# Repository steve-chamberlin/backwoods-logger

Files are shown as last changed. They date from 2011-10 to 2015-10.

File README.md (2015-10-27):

 
 




The Backwoods Logger is a programmable device for measuring and graphing temperature, air pressure, and altitude. It's designed for hikers, backpackers, climbers, skiers, trail runners, cyclists, kayakers, snowmobilers, horseback riders, and other outdoorsy people interested in environmental data logging over timescales from an hour to a few weeks.

Please visit the [wiki](https://github.com/steve-chamberlin/backwoods-logger/wiki) for complete details and documentation.

#### Features ####
  * Graphs of temperature, pressure, and altitude over time
  * Three graph time scales: past 2 hours, past 10 hours, past 2.5 days
  * Current rate of ascent/descent
  * Estimated time of arrival at a user-defined altitude
  * Weather forecast
  * Station pressure and pressure at sea level
  * Snapshot feature – make a permanent record of date, time, altitude, temperature, and pressure at important waypoints
  * Current date and time display
  * Imperial or metric units option
  * Battery voltage indicator
  * Sound on/off control
  * 3 to 6 month battery life, depending on usage
  * Temperature measurements in 0.5 degree steps, from -10F to 117.5F (-23C to 48C)
  * Air pressure measurements in 0.01 in-Hg steps, from 5.9 to 36.12 in-Hg (170 to 1250 millibars)
  * Altitude (calculated from air pressure) measurements in 2 ft steps, from -1384 ft to 14999 ft (-300 to 4500 meters)
  * Download graph data to your PC using the optional [BLsync](https://github.com/steve-chamberlin/backwoods-logger/wiki/BLsync) adapter

Don't see the feature you want? Join the project and help create it! Also check out the list of [development ideas](https://github.com/steve-chamberlin/backwoods-logger/wiki/Development-Needs) for suggestions on where you could help out.

Two versions of the Backwoods Logger design are available:

#### Logger Mini ####
![](http://www.bigmessowires.com/new-logger-mini-graph-300.png)
  * 128 x 64 OLED display
  * 1.9 x 1.1 x 0.7 inches (48 x 28 x 17 mm) - very small!
  * 0.7 ounces (19g) including AAA battery

#### Logger Classic ####

  * 84 x 48 LCD display
  * 2.75 x 1.75 x 0.75 inches (70 x 45 x 17 mm)
  * 1.3 ounces (37g) including CR2032 battery
  * all through-hole parts, easy to assemble

#### Hardware ####
Both versions of the Backwoods Logger use the Atmel ATmega328P microcontroller and Bosch BMP085 pressure / temperature sensor. The ATmega328P is the same microcontroller used in the popular Arduino electronics prototyping system. Anyone with some programming experience can modify the Logger's C source code to change its behavior or add new features.

The Backwoods Logger was originally developed as a [Big Mess o' Wires](http://www.bigmessowires.com) project.

#### Building the Logger ####
Because the Backwoods Logger is an open hardware project, you can build one yourself using the plans provided here. See the [assembly instructions](https://github.com/steve-chamberlin/backwoods-logger/wiki/Assembly-Instructions) for more details.

#### Buying a Logger ####
Don't want to build your own? [Steve Chamberlin](mailto:steve@bigmessowires.com) made a small production run of Backwoods Logger Mini units and [BLsync](https://github.com/steve-chamberlin/backwoods-logger/wiki/BLsync) adapter boards, and is offering them for sale. The price is $49 for an assembled Logger Mini, and $6 for an assembled blsync adapter. Contact Steve for more details or to make a purchase.

Need a PCB? Steve is also selling bare Logger Mini PCBs for $3.

#### More ####
Want to learn more, or maybe help with the project? Join the [Backwoods Logger public discussion group](http://groups.google.com/group/backwoods-logger-discuss).

---

Youtube video of the Backwoods Logger Classic in action:

(http://www.youtube.com/watch?v=xRp--kYWmEM)

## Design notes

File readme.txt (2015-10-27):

Backwoods Logger 
October 15, 2011
Steve Chamberlin
steve@bigmessowires.com
www.bigmessowires.com

DOCUMENTATION
  
The Backwoods Logger is an open source, open hardware project. See the project homepage at 
http://github.com/steve-chamberlin/backwoods-logger for the latest assembly instructions, the parts list, 
programmer's guide, and user manual.

DISCUSSION

Join the Backwoods Logger public discussion mailing list at http://groups.google.com/group/backwoods-logger-discuss

LICENSING

The Backwoods Logger software is offered under the MIT license, whose terms appear in the source code files. The
Backwoods Logger schematics, board layout files, Gerber files, and other content files are offered under the Creative
Commons Attribution 3.0 license (CC BY 3.0), whose terms can be viewed at http://creativecommons.org/licenses/by/3.0/.

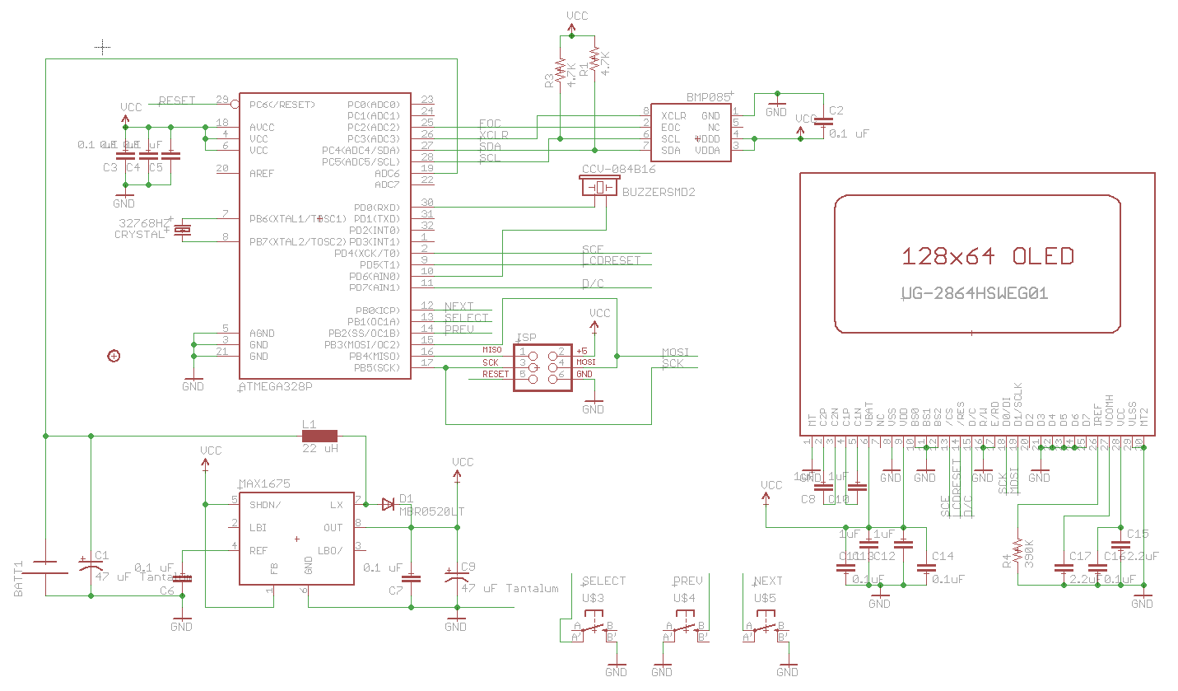
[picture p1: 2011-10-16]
Logger Mini files/schematic.png

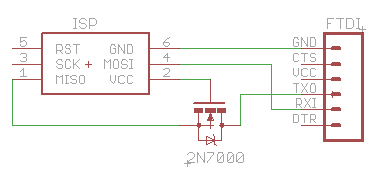
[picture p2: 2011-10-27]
blsync/schematic.png

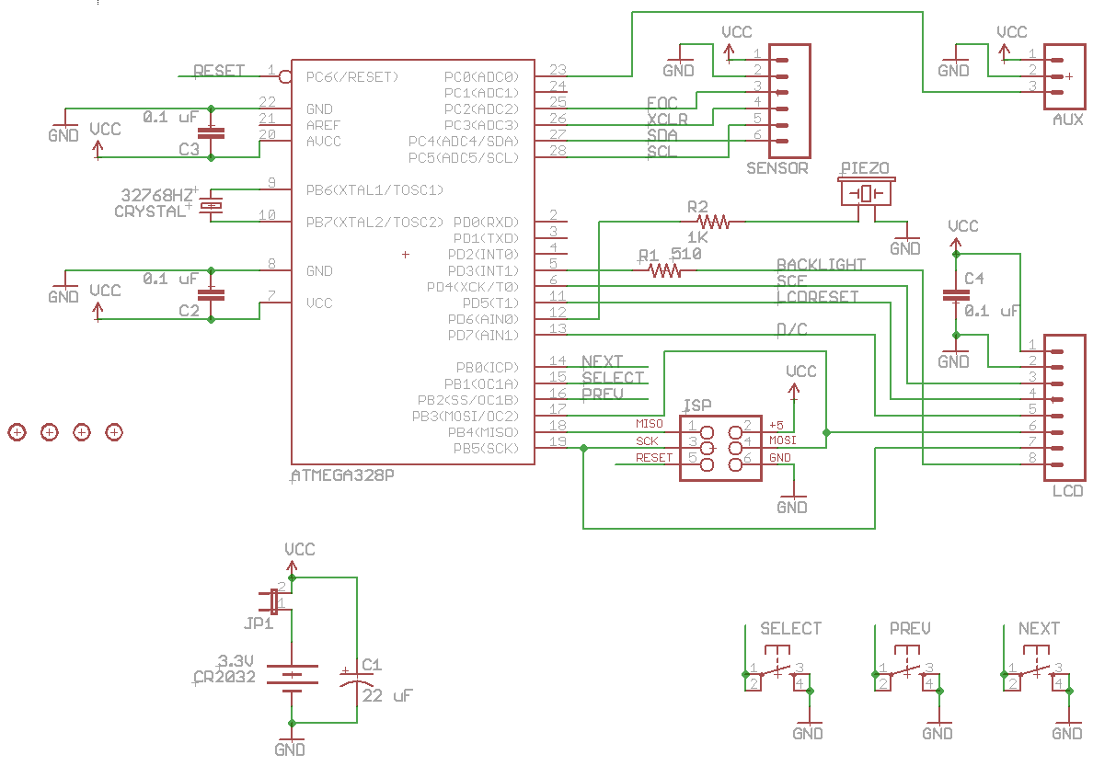
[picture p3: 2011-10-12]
Logger Classic files/schematic.png

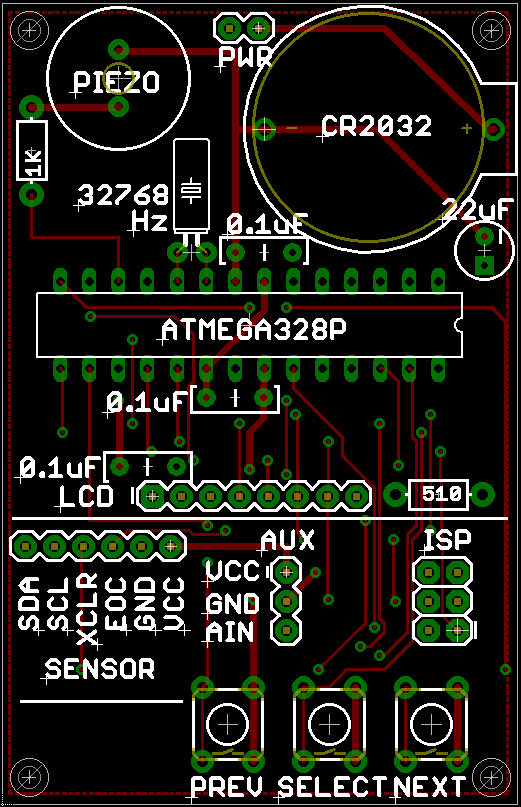
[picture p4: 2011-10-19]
Logger Classic files/board-top.png

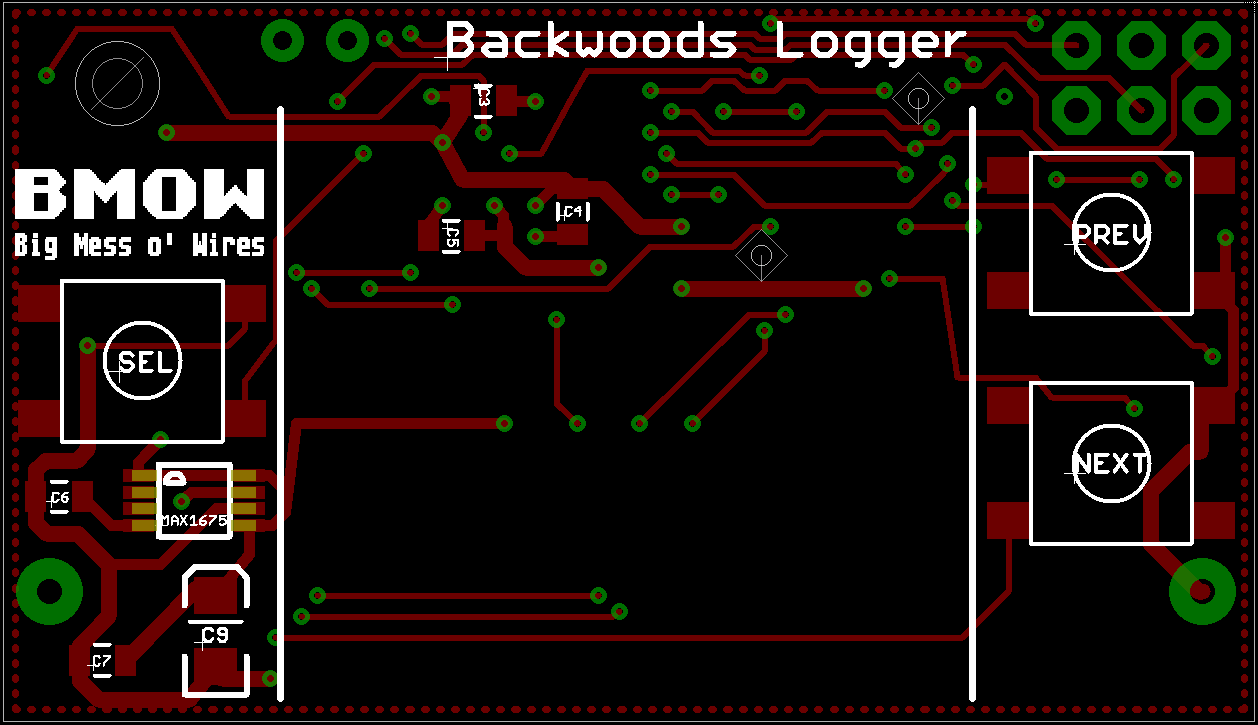
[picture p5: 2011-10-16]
Logger Mini files/board-top.png

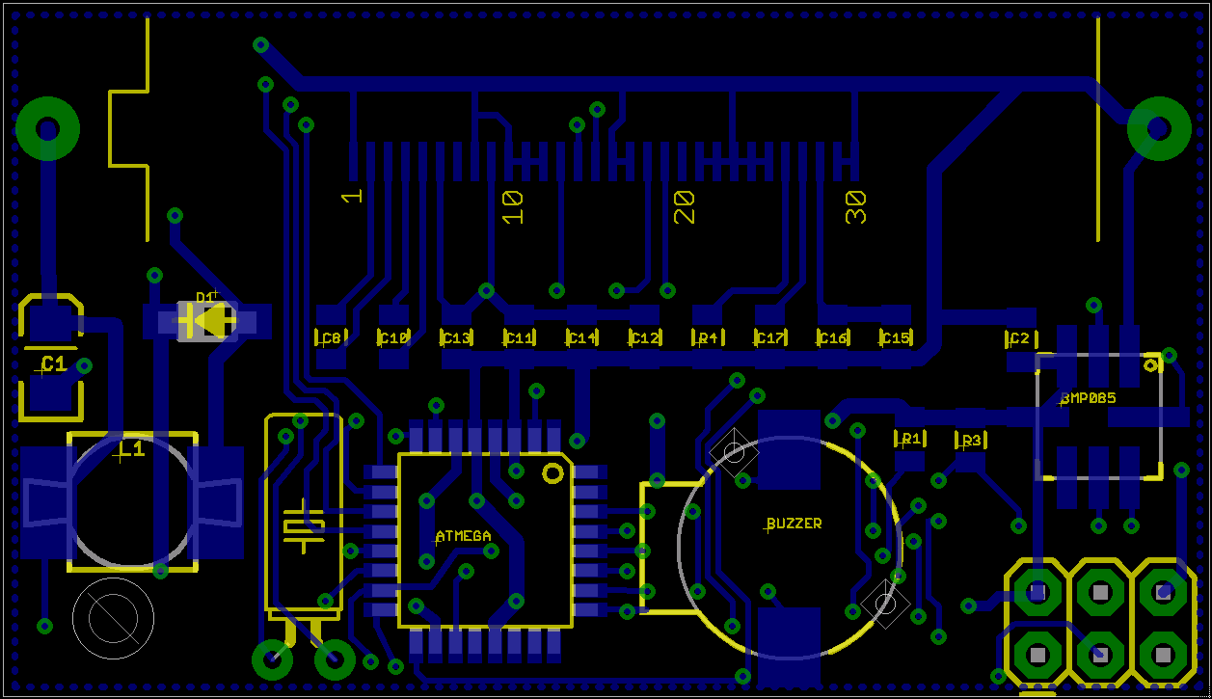
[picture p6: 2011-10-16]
Logger Mini files/board-bottom.png

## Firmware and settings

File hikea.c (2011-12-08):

/*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
  The above copyright notice and this permission notice shall be included in all copies or substantial portions of the Product. 

  THE PRODUCT IS PROVIDED "AS IS", WITHOUT WARRANTY OF ANY KIND, EXPRESS OR IMPLIED, INCLUDING BUT NOT LIMITED TO THE WARRANTIES OF 
  MERCHANTABILITY, FITNESS FOR A PARTICULAR PURPOSE AND NONINFRINGEMENT. IN NO EVENT SHALL THE AUTHORS OR COPYRIGHT HOLDERS BE LIABLE FOR 
  ANY CLAIM, DAMAGES OR OTHER LIABILITY, WHETHER IN AN ACTION OF CONTRACT, TORT OR OTHERWISE, ARISING FROM, OUT OF OR IN CONNECTION WITH 
  THE PRODUCT OR THE USE OR OTHER DEALINGS IN THE PRODUCT.
*/

#include <avr/interrupt.h>
#include <avr/io.h>
#include <avr/sleep.h>
#include <util/atomic.h>
#include <util/delay.h>
#include <stdlib.h>
#include <string.h>

#include "hikea.h"
#include "avrsensors.h"
#include "config.h"


#ifdef NOKIA_LCD
#include "noklcd.h"
#include "logo-84.h"
#endif
#ifdef SSD1306_LCD
#include "ssd1306.h"
#include "logo-128.h"
#endif

#ifdef SHAKE_SENSOR
#include "shake.h"
#endif

#include "bmp085.h"
#include "avrsensors.h"
#include "sampling.h"
#include "clock.h"
#include "speaker.h"
#include "serial.h"

#define BUTTON_NEXT PB0
#define BUTTON_SELECT PB1
#define BUTTON_PREV PB2

#define INVALID_RATE 0x7FFFFFFF

#define DEBOUNCE_TIME 25

uint8_t anyButtonDown = 0;
uint32_t lastButtonDownTime = 0;
uint32_t lastButtonUpTime = 0;
uint8_t sleepDelay;

#define UINT_MOD(value, modulus) ((uint8_t)(value) > 0xF0 ? (value) + (modulus) : (uint8_t)(value) >= (modulus) ? (value) - (modulus) : (value))

enum {
	MODE_CURRENT_DATA = 0,
	MODE_ALTITUDE_INFO,
	MODE_ALTITUDE_GRAPH,
	MODE_TEMP_INFO,
	MODE_TEMP_GRAPH,
	MODE_PRESSURE_INFO,
	MODE_PRESSURE_GRAPH,
	MODE_SNAPSHOTS,
	MODE_SYSTEM,
	MODE_TOP_LEVEL_COUNT,
	MODE_DATA_TYPE = MODE_TOP_LEVEL_COUNT,
	MODE_GRAPH,
	MODE_SET_TIME,
	MODE_ENTER_NUMBER,
	MODE_CHOICE
};

volatile uint8_t newSampleNeeded = 1;
volatile uint8_t screenUpdateNeeded = 1;
volatile uint8_t screenClearNeeded = 0;
volatile uint8_t graphClearNeeded = 0;
volatile uint8_t snapshotNeeded = 0;
volatile uint8_t lcdResetNeeded = 0;

volatile uint8_t mode = MODE_CURRENT_DATA;
volatile uint8_t submode = 0;
volatile uint8_t menuLevel = 0;
volatile uint8_t selectedMenuItemIndex = 0;
volatile uint8_t parentSelectedMenuItemIndex = 0;
volatile uint8_t subMenuItemIndex = 0;
volatile uint8_t topMenuItemIndex = 0;
volatile uint8_t exploringGraph = 0;
volatile uint8_t graphCursor = 0;
volatile uint8_t hibernating = 0;
volatile uint8_t unlockState = 0;

// main screen

// system screen	
const char versionStr[] PROGMEM = "1.0.4";

volatile uint8_t setting_second;
volatile uint8_t setting_minute;
volatile uint8_t setting_hour;
volatile uint8_t setting_day;
volatile uint8_t setting_month;
volatile uint8_t setting_year; // year - 2000

// altitude
volatile int16_t altitudeDestination;

// main screen menu
const char exitMenu[] PROGMEM = "Exit Menu";

enum {
	MENU_MAIN_EXIT_MENU = 0,
	MENU_MAIN_SETUP1,
	MENU_MAIN_SETUP2,
	MENU_MAIN_SETUP3,
	MENU_MAIN_SETUP4,
	MENU_MAIN_SETUP5,
	MENU_MAIN_SETUP6
};

const char main1[] PROGMEM = "Line 1 Data";
const char main2[] PROGMEM = "Line 2 Data";
const char main3[] PROGMEM = "Line 3 Data";
const char main4[] PROGMEM = "Line 4 Data";
const char main5[] PROGMEM = "Line 5 Data";
const char main6[] PROGMEM = "Line 6 Data";

const char* mainMenu[] PROGMEM = { 
	exitMenu, main1, main2, main3, main4, main5, main6, NULL 
};

// altitude menu
enum {
	MENU_ALTITUDE_EXIT_MENU = 0,
	MENU_ALTITUDE_CALIBRATE,
	MENU_ALTITUDE_SET_GOAL
};

const char altitude1[] PROGMEM = "Calibrate";
const char altitude2[] PROGMEM = "Set Destination";
const char altitude2a[] PROGMEM = "Reset Destination";

const char* altitudeMenu[] PROGMEM = { 
	exitMenu, altitude1, altitude2, NULL 
};

// system menu
enum {
	MENU_SYSTEM_EXIT_MENU = 0,
	MENU_SYSTEM_DATE_TIME,
	MENU_SYSTEM_UNITS,
	MENU_SYSTEM_SLEEP_DELAY,
	MENU_SYSTEM_SOUND,
	MENU_SYSTEM_LCD_CONTRAST,
#ifdef LOGGER_CLASSIC	
	MENU_SYSTEM_LCD_BIAS,
	MENU_SYSTEM_LCD_TEMP_COEF,
#endif	
	MENU_SYSTEM_RESTORE_DEFAULTS,
	MENU_SYSTEM_ERASE_ALL_GRAPHS,
	MENU_SYSTEM_COUNT
};

const char system1[] PROGMEM = "Date and Time";
const char system2[] PROGMEM = "Measurement Units";
const char system3[] PROGMEM = "Sleep Delay";
const char system4[] PROGMEM = "Sound";
const char system5[] PROGMEM = "LCD Contrast";
#ifdef LOGGER_CLASSIC
const char system6[] PROGMEM = "LCD Bias";
const char system7[] PROGMEM = "LCD Temp Coef";
#endif
const char system8[] PROGMEM = "Restore Defaults";
const char system9[] PROGMEM = "Erase All Data";

const char* systemMenu[] PROGMEM = { 
	exitMenu, 
	system1, 
	system2, 
	system3, 
	system4, 
	system5, 
#ifdef LOGGER_CLASSIC	
	system6, 
	system7, 
#endif	
	system8, 
	system9, 
	NULL 
};

// data type menu

enum {
	MENU_DATA_EXIT_MENU = 0,
	MENU_DATA_TEMP,
	MENU_DATA_ALTITUDE,
	MENU_DATA_RATE_OF_ASCENT,
	MENU_DATA_TIME_TO_DESTINATION,
	MENU_DATA_PRESSURE_STATION,
	MENU_DATA_PRESSURE_SEALEVEL,
	MENU_DATA_TIME_OF_DAY,
	MENU_DATA_DATE_AND_TIME,
	MENU_DATA_TEMP_TREND,
	MENU_DATA_PRESSURE_TREND,
	MENU_DATA_FORECAST,
#ifdef SHAKE_SENSOR
	MENU_DATA_TRIP_TIME,
#endif	
#ifdef TRACK_DAILYHIGHLOW
	MENU_DATA_TEMP_DAILYHIGHLOW,
	MENU_DATA_PRESSURE_DAILYHIGHLOW,
	MENU_DATA_ALTITUDE_DAILYHIGHLOW,
#endif

	MENU_DATA_EMPTY
};

const char data1[] PROGMEM = "Temperature";
const char data2[] PROGMEM = "Altitude";
const char data3[] PROGMEM = "Rate of Ascent";
const char data4[] PROGMEM = "Time to Destination";
const char data5[] PROGMEM = "Station Pressure";
const char data6[] PROGMEM = "Sea Level Pressure";
const char data7[] PROGMEM = "Time of Day";
const char data8[] PROGMEM = "Date and Time";
const char data9[] PROGMEM = "Temperature Trend";
const char data10[] PROGMEM = "Pressure Trend";
const char data11[] PROGMEM = "Weather Forecast";
const char data12[] PROGMEM = "Empty";
#ifdef SHAKE_SENSOR
const char data13[] PROGMEM = "Trip Time";
#endif
#ifdef TRACK_DAILYHIGHLOW
const char data14[] PROGMEM = "Temp Daily High/Low";
const char data15[] PROGMEM = "Press Daily High/Low";
const char data16[] PROGMEM = "Alt Daily High/Low";
#endif


const char* dataMenu[] PROGMEM = { 
	exitMenu, data1, data2, data3, data4, data5, data6, data7, data8, data9, data10, data11, 
#ifdef SHAKE_SENSOR
	data13,
#endif	
#ifdef TRACK_DAILYHIGHLOW
	data14, data15, data16,
#endif
	data12, NULL 
};

volatile uint8_t mainScreenDataType[6];

// snapshots menu

enum {
	MENU_SNAPSHOTS_EXIT_MENU = 0,
	MENU_SNAPSHOTS_VIEW,
	MENU_SNAPSHOTS_TAKE
};

const char snapshots1[] PROGMEM = "View Snapshot Log";
const char snapshots2[] PROGMEM = "Take Snapshot";

const char* snapshotsMenu[] PROGMEM = { 
	exitMenu, snapshots1, snapshots2, NULL 
};

// graph menu

enum {
	MENU_GRAPH_EXIT_MENU = 0,
	MENU_GRAPH_EXPLORE,
	MENU_GRAPH_TYPE,
	MENU_GRAPH_YAXIS_MIN,
	MENU_GRAPH_YAXIS_MAX
};

const char graph1[] PROGMEM = "Explore Graph";
const char graph2[] PROGMEM = "Drawing Style";
const char graph3[] PROGMEM = "Custom Y-Axis Min";
const char graph4[] PROGMEM = "Custom Y-Axis Max";
const char graph3a[] PROGMEM = "Auto Y-Axis Min";
const char graph4a[] PROGMEM = "Auto Y-Axis Max";

const char* graphMenu[] PROGMEM = {
	exitMenu, graph1, graph2, graph3, graph4, NULL
};

// rates of change
enum {
	CHANGE_SOARING = 0,
	CHANGE_RISING_QUICKLY,
	CHANGE_RISING,
	CHANGE_RISING_SLOWLY,
	CHANGE_STEADY,
	CHANGE_FALLING_SLOWLY,
	CHANGE_FALLING,
	CHANGE_FALLING_QUICKLY,
	CHANGE_PLUMMETING
};

const char change1[] PROGMEM = "Soaring";
const char change2[] PROGMEM = "Rising Fast";
const char change3[] PROGMEM = "Rising";
const char change4[] PROGMEM = "Rising Slow";
const char change5[] PROGMEM = "Steady";
const char change6[] PROGMEM = "Falling Slow";
const char change7[] PROGMEM = "Falling";
const char change8[] PROGMEM = "Falling Fast";
const char change9[] PROGMEM = "Plummeting";

const char* changeStrings[] PROGMEM = { 
	change1, change2, change3, change4, change5, change6, change7, change8, change9
};
	
const char** modeMenus[] = {
	mainMenu, altitudeMenu, 0, 0, 0, 0, 0, snapshotsMenu, systemMenu, dataMenu, graphMenu
};
	
uint8_t parentMode;	
uint8_t grandparentMode;
int16_t enterNumberMax;
int16_t enterNumberMin;
int16_t enterNumberValue;
PGM_P enterNumberUnits;
char* enterNumberPrompt;

char* choicePrompt;
char* choice1;
char* choice2;


void LcdUtil_ClearLine( uint8_t row, uint8_t ch );
void LcdUtil_ShowMainScreenData( uint8_t row, uint8_t type, uint8_t line_len, uint8_t half_char, uint8_t tiny );



	
void DrawMenu()
{
#ifdef SSD1306_LCD
	const uint8_t menuLines = 7;
	const uint8_t charWidth = 6;
#endif
#ifdef NOKIA_LCD
	const uint8_t menuLines = 5;
	const uint8_t charWidth = 4;
#endif	
	const char** menu = modeMenus[mode];
	uint8_t numMenuItems = 0;
	while (pgm_read_word(&menu[numMenuItems]))
	{
		numMenuItems++;
	}
			
	for (uint8_t i=0; i<menuLines && topMenuItemIndex+i < numMenuItems; i++)
	{
		const char* pMenuItem = (PGM_P)pgm_read_word(&menu[topMenuItemIndex+i]);
		
		// special case for Set/Reset Altitude Destination menu item
		if (mode == MODE_ALTITUDE_INFO && topMenuItemIndex+i == MENU_ALTITUDE_SET_GOAL && altitudeDestination != INVALID_SAMPLE)
		{
			pMenuItem = altitude2a;
		}	
		
		// special case for Custom/Auto Y-axis menu items
		if (mode == MODE_GRAPH)
		{	
			uint8_t graphType = parentMode == MODE_ALTITUDE_GRAPH ? GRAPH_ALTITUDE : parentMode == MODE_TEMP_GRAPH ? GRAPH_TEMPERATURE : GRAPH_PRESSURE;
			
			if (topMenuItemIndex+i == MENU_GRAPH_YAXIS_MIN && graphYMin[graphType] != INVALID_SAMPLE)
			{
				pMenuItem = graph3a;
			}
			if (topMenuItemIndex+i == MENU_GRAPH_YAXIS_MAX && graphYMax[graphType] != INVALID_SAMPLE)
			{
				pMenuItem = graph4a;
			}
		}
						
		LcdUtil_ClearLine( i+1, topMenuItemIndex+i == selectedMenuItemIndex ? 0x7F : 0x00 );
		
		LcdGoto(4, i+1);
		char str[22];
		strncpy_P(str, pMenuItem, 21);
		LcdTinyString(str, topMenuItemIndex+i == selectedMenuItemIndex ? TEXT_INVERSE : TEXT_NORMAL);
		
		// draw up/down arrows if there are more menu choices than fit on the screen
		if (i == 0 && topMenuItemIndex != 0)
		{
			LcdGoto(LCD_WIDTH-charWidth,i+1);
			LcdTinyString("^", topMenuItemIndex == selectedMenuItemIndex ? TEXT_INVERSE : TEXT_NORMAL);
		}
	
		if (i==menuLines-1 && topMenuItemIndex+i+1 != numMenuItems)
		{
			LcdGoto(LCD_WIDTH-charWidth,i+1);
			LcdTinyString(";", topMenuItemIndex+i == selectedMenuItemIndex ? TEXT_INVERSE : TEXT_NORMAL);			
		}
	}			
}

void HandleSetTimeSelect()
{
	SpeakerBeep(BEEP_ENTER);
	selectedMenuItemIndex++;
	if (selectedMenuItemIndex == 7)
	{
		ATOMIC_BLOCK(ATOMIC_RESTORESTATE)
		{
			clock_second = setting_second;
			clock_minute = setting_minute;
			clock_hour = setting_hour;
			clock_day = setting_day;
			clock_month = setting_month;
			clock_year = setting_year; 
		}
		
		mode = MODE_SYSTEM;
		menuLevel = 0;
		screenClearNeeded = 1;				
	}	
}

void HandleSetTimePrevNext(uint8_t step)
{
	uint8_t februaryLength = (setting_year % 4 == 0) ? 29 : 28;
	uint8_t monthLength;
	if (setting_month == 2)
		monthLength = februaryLength;
	else if (setting_month == 4 || setting_month == 6 || setting_month == 9 || setting_month == 11)
		monthLength = 30;
	else
		monthLength = 31;
	
	uint8_t pm = setting_hour >= 12;
			
	switch (selectedMenuItemIndex)
	{
		case 0:
			setting_month += step;
			setting_month = 1+UINT_MOD(setting_month-1, 12);
			break;
		case 1:
			setting_day += step;
			setting_day = 1+UINT_MOD(setting_day-1, monthLength);
			break;	
		case 2:
			setting_year += step;
			break;
		case 3:
			setting_hour += step;
			if (pm)
				setting_hour = 12+UINT_MOD(setting_hour-12, 12);
			else
				setting_hour = UINT_MOD(setting_hour, 12);
			break;
		case 4:
			setting_minute += step;
			setting_minute = UINT_MOD(setting_minute, 60);
			break;
		case 5:
			setting_second += step;
			setting_second = UINT_MOD(setting_second, 60);
			break;
		case 6:
			if (step == 1)
				setting_hour += 12;
			else
				setting_hour -= 12;
			setting_hour = UINT_MOD(setting_hour, 24);
			break;			
	}	
}	

void StartEnterNumber(int16_t vMin, int16_t vMax, int16_t value, PGM_P units)
{
	parentMode = mode;
	enterNumberMax = vMax;
	enterNumberMin = vMin;
	enterNumberValue = value;	
	enterNumberUnits = units;
	enterNumberPrompt = NULL;
	
	mode = MODE_ENTER_NUMBER;
}
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
int main(void) 
{		
	// enable the internal pull-up resistors for buttons	
	PORTB |= (1<<BUTTON_NEXT) | (1<<BUTTON_SELECT) | (1<<BUTTON_PREV); 
											
	LcdReset();
	LcdClear();
	LcdPowerSave(0);
	_delay_ms(20);
		
	ClockInit();
	SamplingInit(0);
	
#if TRACK_DAILYHIGHLOW
	ResetHighLow();
#endif	

	SpeakerInit();
	SerialInit();
	InitSettings();
	
#ifdef SHAKE_SENSOR
	ShakeInit();
#endif
	
	sei();	

	LcdGoto(0, 0);
	LcdString("Sensor init...");
	
	while (bmp085Init() == 0) 
	{
#ifdef SENSOR_ERROR_REPORT		
		static uint8_t try = 0;
		char str[21];
		
		LcdGoto(0,1);
		strcpy_P(str, PSTR("Sensor error"));
		LcdString(str);
			
		LcdGoto(0,2);
		strcpy_P(str, PSTR("Retry "));
		itoa(try, &str[strlen(str)], 10);
		LcdString(str);
		
		_delay_ms(2000);
		try++;		
#endif		
	}

	// initialize timer 2 to use an external 32768 Hz crystal 
    ASSR |= (1 << AS2); // use TOSC1/TOSC2 oscillator as timer 2 clock	
	ASSR &= ~(1 << EXCLK); // use a crystal oscillator rather than an external clock
    TCCR2A = 0; // normal counter mode
	TCCR2B = (1<<CS21) | (1<<CS20); // use oscillator/32 
    while (ASSR & 0x0F) {} // wait until all the asynchronous busy flags (low 4 bits) are zero
    _delay_ms (10); // wait until oscillator has stabilized   
    TIFR2 = (1 << TOV2); // clear the timer 2 interrupt flags 
    TIMSK2 = (1 << TOIE2); // enable timer 2 overflow interrupt

	// set the pin change interrupt masks for buttons
	PCMSK0 |= (1<<PCINT0) | (1<<PCINT1) | (1<<PCINT2);
	// set the state change interrupt mask for the serial input
	PCMSK0 |= (1<<PCINT4) ;
	// enable the interrupts
	PCICR |= (1<<PCIE0); 
				
	// disable unused peripherals
	PRR |= (1<<PRTWI) | (1<<PRSPI) | (1<<PRTIM1) | (1<<PRTIM0) | (1<<PRUSART0) | (1<<PRADC);
		
	newSampleNeeded = 1;
					
	while (1) 
	{	
		if (lcdResetNeeded)
		{
			lcdResetNeeded = 0;
			LcdReset();
			LcdClear();
			LcdPowerSave(0);
			screenUpdateNeeded = 1;
		}
		
		if (graphClearNeeded)
		{
			graphClearNeeded = 0;
			LcdGoto(0,0);
			LcdClear();
			SamplingInit(1);
		}
		
#ifdef SHAKE_SENSOR		
		// update the shake state once per minute, using the newSampleNeeded flag. 
		// must be done during the main loop, and not interrupt, this the ugly re-use of flag.
		if (newSampleNeeded)
		{
			ShakeUpdate();
		}
#endif	

#if TRACK_DAILYHIGHLOW
		// Check for a new day once per minute so we can reset the daily high/low
		{
			static uint8_t prev_today = 0;
			uint8_t today = clock_day;
			if( prev_today != today )
			{
				prev_today = today;
				ResetHighLow();
			}
		}
#endif	

		
		// take new sample
		if (newSampleNeeded || snapshotNeeded)
		{		
			short tempc;
			long pressure;
		
			PRR &= ~(1<<PRTWI); // enable I2C
		
			unsigned int ut = bmp085ReadUT();	
			tempc = bmp085ConvertTemperature(ut);
			unsigned long up = bmp085ReadUP();
			pressure = bmp085ConvertPressure(up);
						
			PRR |= (1<<PRTWI); // disable I2C
				
			if (newSampleNeeded)
			{
				StoreSample(tempc, pressure);		
			}
						
			if (snapshotNeeded)
			{
				uint32_t packedYearMonthDayHourMin;
				ATOMIC_BLOCK(ATOMIC_RESTORESTATE)
				{
					packedYearMonthDayHourMin = clock_year;
					packedYearMonthDayHourMin = packedYearMonthDayHourMin*13 + clock_month;
					packedYearMonthDayHourMin = packedYearMonthDayHourMin*32 + clock_day;
					packedYearMonthDayHourMin = packedYearMonthDayHourMin*24 + clock_hour;
					packedYearMonthDayHourMin = packedYearMonthDayHourMin*60 + clock_minute;
				}
				
				StoreSnapshot(tempc, pressure, packedYearMonthDayHourMin);
			}
			
			newSampleNeeded = 0;
			snapshotNeeded = 0;
		}
		
		// clear display
		if (screenClearNeeded)
		{
			screenClearNeeded = 0;
			LcdClear();
		}
		
		// update display
		if (screenUpdateNeeded)
		{	
			screenUpdateNeeded = 0;
			DrawModeScreen();
		}
		
		// keep sleeping until a redraw is required or a new sample is needed
		while (!newSampleNeeded && !screenUpdateNeeded && !snapshotNeeded)
		{
			if (!speaker_in_use)
			{
				set_sleep_mode(SLEEP_MODE_PWR_SAVE);
				sleep_mode();		
			}	
		}			
	}
}

long GetRateOfAscent()
{
	// get altitude 10 minutes ago
	const uint8_t ascentRateWindow = 10; // max window size is SAMPLES_PER_GRAPH-1
	uint8_t index = GetTimescaleNextSampleIndex(0); // get next sample index from the 1-minute timescale
	index--; // index of most recent sample
	index -= ascentRateWindow;
	if (index > SAMPLES_PER_GRAPH)
		index += SAMPLES_PER_GRAPH;
	Sample* pPastSample = GetSample(0, index);
			
	long ratePerMinute = 0;
	if (pPastSample->altitude)
	{	
		long pastAltitude = 200L * SAMPLE_TO_ALTITUDE(pPastSample->altitude);
				
		// compute rate of ascent
		ratePerMinute = ((long)(last_altitude*100) - pastAltitude) / ascentRateWindow;
		ratePerMinute = (ratePerMinute + 50) / 100;
				
		return ratePerMinute;
	}
	else
	{
		return INVALID_RATE;
	}	
}

long GetTemperatureTrend()
{
	// get temp 60 minutes ago
	const uint8_t window = 60; // max window size is SAMPLES_PER_GRAPH-1
	uint8_t index = GetTimescaleNextSampleIndex(0); // get next sample index from the 1-minute timescale
	index--; // index of most recent sample
	index -= window;
	if (index > SAMPLES_PER_GRAPH)
		index += SAMPLES_PER_GRAPH;
	Sample* pPastSample = GetSample(0, index);
			
	long ratePerHour = 0;
	if (pPastSample->temperature)
	{	
		long pastTemperature = SAMPLE_TO_TEMPERATURE(pPastSample->temperature);
				
		// compute rate of change 
		ratePerHour = 60 * (last_temperature - pastTemperature) / window;
		return ratePerHour;
	}
	else
	{
		return INVALID_RATE;
	}
}

long GetPressureTrend1()
{
	// get pressure 60 minutes ago
	const uint8_t window = 60; // max window size is SAMPLES_PER_GRAPH-1
	uint8_t index = GetTimescaleNextSampleIndex(0); // get next sample index from the 1-minute timescale
	index--; // index of most recent sample
	index -= window;
	if (index > SAMPLES_PER_GRAPH)
		index += SAMPLES_PER_GRAPH;
	Sample* pPastSample = GetSample(0, index);
			
	long ratePerHour = 0;
	if (pPastSample->pressure)
	{	
		long pastPressure = 50L * SAMPLE_TO_PRESSURE(pPastSample->pressure); // put in units of mb * 100
				
		// compute rate of change
		long pressure = last_pressure; // units of mb*100
		ratePerHour = 60 * (pressure - pastPressure) / window;
		return ratePerHour;
	}
	else
	{
		return INVALID_RATE;
	}
}

// TODO: save memory by combining this with GetPressureTrend1()
long GetPressureTrend5()
{
	// get pressure 300 minutes ago
	const uint8_t window = 75; // max window size is SAMPLES_PER_GRAPH-1
	uint8_t index = GetTimescaleNextSampleIndex(1); // get next sample index from the 4-minute timescale
	index--; // index of most recent sample
	index -= window;
	if (index > SAMPLES_PER_GRAPH)
		index += SAMPLES_PER_GRAPH;
	Sample* pPastSample = GetSample(1, index);
			
	long ratePerHour = 0;
	if (pPastSample->pressure)
	{	
		long pastPressure = 50L * SAMPLE_TO_PRESSURE(pPastSample->pressure); // put in units of mb * 100
				
		// compute rate of change
		long pressure = last_pressure; // units of mb*100
		ratePerHour = 60 * (pressure - pastPressure) / (window * 4);
		return ratePerHour;
	}
	else
	{
		return INVALID_RATE;
	}
}

uint8_t GetPressureChangeType(long mbX100PerHour)
{
	uint8_t pressureChange;
	if (mbX100PerHour == INVALID_RATE)
	{
		pressureChange = CHANGE_STEADY;
	}
	else if (mbX100PerHour > 200)
	{
		// 2.01+ clearing from storm, strong winds (2.0 mb/hr = +0.059 in/hr)
		pressureChange = CHANGE_SOARING;
	}
	else if (mbX100PerHour > 120)
	{
		// 1.21 - 2.00 clearing from storm, moderate winds (1.2 mb/hr = +0.036 in/hr)
		pressureChange = CHANGE_RISING_QUICKLY;
	}
	else if (mbX100PerHour > 53)
	{
		// 0.54 - 1.20 (0.53mb/hr = 0.016 in/hr)
		pressureChange = CHANGE_RISING;
	}
	else if (mbX100PerHour > 0)
	{
		// 0.01 - 0.53
		pressureChange = CHANGE_RISING_SLOWLY;
	}
	else if (mbX100PerHour == 0)
	{
		pressureChange = CHANGE_STEADY;
	}	
	else if (mbX100PerHour > -54)
	{
		// -0.53 to -0.01
		pressureChange = CHANGE_FALLING_SLOWLY;
	}
	else if (mbX100PerHour > -121)
	{
		// -1.20 to -0.54
		pressureChange = CHANGE_FALLING;
	}
	else if (mbX100PerHour > -201)
	{
		// -2.00 to -1.21, stormy, windy
		pressureChange = CHANGE_FALLING_QUICKLY;
	}
	else
	{
		// -2.01+ very stormy, strong winds
		pressureChange = CHANGE_PLUMMETING;
	}
			
	return pressureChange;
}
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

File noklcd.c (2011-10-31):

/*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
  The above copyright notice and this permission notice shall be included in all copies or substantial portions of the Product. 

  THE PRODUCT IS PROVIDED "AS IS", WITHOUT WARRANTY OF ANY KIND, EXPRESS OR IMPLIED, INCLUDING BUT NOT LIMITED TO THE WARRANTIES OF 
  MERCHANTABILITY, FITNESS FOR A PARTICULAR PURPOSE AND NONINFRINGEMENT. IN NO EVENT SHALL THE AUTHORS OR COPYRIGHT HOLDERS BE LIABLE FOR 
  ANY CLAIM, DAMAGES OR OTHER LIABILITY, WHETHER IN AN ACTION OF CONTRACT, TORT OR OTHERWISE, ARISING FROM, OUT OF OR IN CONNECTION WITH 
  THE PRODUCT OR THE USE OR OTHER DEALINGS IN THE PRODUCT.
*/

#ifdef NOKIA_LCD

// Nokia 5110 monochrome LCD 84x46

#include <avr/pgmspace.h>
#include <util/atomic.h>
#include <string.h>

#include "noklcd.h"
#include "sampling.h"
#include "clock.h"

// port B
#define LCD_PIN_SDIN PB3
#define LCD_PIN_SCLK PB5

// port D
#define LCD_PIN_DC PD7
#define LCD_PIN_SCE PD4
#define LCD_PIN_RESET PD5
#define LCD_PIN_BACKLIGHT PD3

volatile uint8_t lcd_vop;
volatile uint8_t lcd_bias;
volatile uint8_t lcd_tempCoef;

volatile int16_t graphCurrentYMin;
volatile int16_t graphCurrentYMax;
volatile int16_t graphYMin[GRAPH_COUNT];
volatile int16_t graphYMax[GRAPH_COUNT];
volatile uint8_t graphDrawPoints[GRAPH_COUNT];

static const prog_uint8_t tiny_font[][3] = {

	{0x00,0x00,0x00}, // 20  
	{0x00,0x17,0x00}, // 21 !
	{0x03,0x00,0x03}, // 22 "
	{0x1f,0x0a,0x1f}, // 23 #
	{0x0a,0x1f,0x05}, // 24 $
	{0x09,0x04,0x12}, // 25 %
	{0x0f,0x17,0x1c}, // 26 &
	{0x00,0x03,0x03}, // 27 ' -> degree
	{0x00,0x0e,0x11}, // 28 (
	{0x11,0x0e,0x00}, // 29 )
	{0x05,0x02,0x05}, // 2a *
	{0x04,0x0e,0x04}, // 2b +
	{0x10,0x08,0x00}, // 2c ,
	{0x04,0x04,0x04}, // 2d -		
	{0x00,0x10,0x00}, // 2e .	
	{0x18,0x04,0x03}, // 2f /				
	{0x1e,0x11,0x0f}, // 30 0
	{0x02,0x1f,0x00}, // 31 1
	{0x19,0x15,0x12}, // 32 2
	{0x15,0x15,0x0a}, // 33 3
	{0x07,0x04,0x1f}, // 34 4
	{0x17,0x15,0x09}, // 35 5		
	{0x1e,0x15,0x1d}, // 36 6
	{0x19,0x05,0x03}, // 37 7
	{0x1f,0x15,0x1f}, // 38 8
	{0x17,0x15,0x0f}, // 39 9	
	{0x00,0x0a,0x00}, // 3a :
	{0x04,0x0c,0x04}, // 3b ;	-> down arrow	
	{0x04,0x0e,0x1f}, // 3c <
	{0x0a,0x0a,0x0a}, // 3d =
	{0x1f,0x0e,0x04}, // 3e >
	{0x01,0x15,0x03}, // 3f ?			
	{0x0e,0x15,0x16}, // 40 @
	{0x1e,0x05,0x1e}, // 41 A
	{0x1f,0x15,0x0a}, // 42 B
	{0x0e,0x11,0x11}, // 43 C
	{0x1f,0x11,0x0e}, // 44 D
	{0x1f,0x15,0x15}, // 45 E
	{0x1f,0x05,0x05}, // 46 F
	{0x0e,0x15,0x1d}, // 47 G
	{0x1f,0x04,0x1f}, // 48 H
	{0x11,0x1f,0x11}, // 49 I
	{0x08,0x10,0x0f}, // 4a J
	{0x1f,0x04,0x1b}, // 4b K
	{0x1f,0x10,0x10}, // 4c L
	{0x1f,0x06,0x1f}, // 4d M
	{0x1f,0x0e,0x1f}, // 4e N		
	{0x0e,0x11,0x0e}, // 4f O	
	{0x1f,0x05,0x02}, // 50 P				
	{0x0e,0x19,0x1e}, // 51 Q
	{0x1f,0x0d,0x16}, // 52 R
	{0x12,0x15,0x09}, // 53 S
	{0x01,0x1f,0x01}, // 54 T
	{0x0f,0x10,0x1f}, // 55 U
	{0x07,0x18,0x07}, // 56 V		
	{0x1f,0x0c,0x1f}, // 57 W
	{0x1b,0x04,0x1b}, // 58 X
	{0x03,0x1c,0x03}, // 59 Y
	{0x19,0x15,0x13}, // 5a Z	
	{0x1f,0x10,0x10}, // 5b [
	{0x02,0x04,0x08}, // 5c backslash
	{0x10,0x10,0x1f}, // 5d ]
	{0x04,0x06,0x04}, // 5e ^
	{0x10,0x10,0x10}, // 5f _
	{0x00,0x03,0x03}, // 60 ` -> degree
	{0x1a,0x16,0x1c}, // 61 a
	{0x1f,0x12,0x0c}, // 62 b
	{0x0c,0x12,0x12}, // 63 c
	{0x0c,0x12,0x1f}, // 64 d
	{0x0c,0x1a,0x16}, // 65 e
	{0x04,0x1e,0x05}, // 66 f
	{0x0c,0x2a,0x1e}, // 67 g
	{0x1f,0x02,0x1c}, // 68 h
	{0x00,0x1d,0x00}, // 69 i
	{0x10,0x20,0x1d}, // 6a j 
	{0x1f,0x0c,0x12}, // 6b k
	{0x11,0x1f,0x10}, // 6c l
	{0x1e,0x0e,0x1e}, // 6d m
	{0x1e,0x02,0x1c}, // 6e n
	{0x0c,0x12,0x0c}, // 6f o
	{0x3e,0x12,0x0c}, // 70 p
	{0x0c,0x12,0x3e}, // 71 q
	{0x1c,0x02,0x02}, // 72 r
	{0x14,0x1e,0x0a}, // 73 s
	{0x02,0x1f,0x12}, // 74 t
	{0x0e,0x10,0x1e}, // 75 u
	{0x0e,0x18,0x0e}, // 76 v
	{0x1e,0x1c,0x1e}, // 77 w
	{0x12,0x0c,0x12}, // 78 x
	{0x06,0x28,0x1e}, // 79 y
	{0x1a,0x1f,0x16}, // 7a z															
};
	
static const prog_uint8_t ASCII[][5] = {
	 {0x00, 0x00, 0x00, 0x00, 0x00} // 20  
	,{0x00, 0x00, 0x5f, 0x00, 0x00} // 21 !
	,{0x00, 0x07, 0x00, 0x07, 0x00} // 22 "
	,{0x14, 0x7f, 0x14, 0x7f, 0x14} // 23 #
	,{0x24, 0x2a, 0x7f, 0x2a, 0x12} // 24 $
	,{0x23, 0x13, 0x08, 0x64, 0x62} // 25 %
	,{0x36, 0x49, 0x55, 0x22, 0x50} // 26 &
	,{0x00, 0x05, 0x03, 0x00, 0x00} // 27 '
	,{0x00, 0x1c, 0x22, 0x41, 0x00} // 28 (
	,{0x00, 0x41, 0x22, 0x1c, 0x00} // 29 )
	,{0x14, 0x08, 0x3e, 0x08, 0x14} // 2a *
	,{0x08, 0x08, 0x3e, 0x08, 0x08} // 2b +
	,{0x00, 0x50, 0x30, 0x00, 0x00} // 2c ,
	,{0x08, 0x08, 0x08, 0x08, 0x08} // 2d -
	,{0x00, 0x60, 0x60, 0x00, 0x00} // 2e .
	,{0x20, 0x10, 0x08, 0x04, 0x02} // 2f /
	,{0x3e, 0x51, 0x49, 0x45, 0x3e} // 30 0
	,{0x00, 0x42, 0x7f, 0x40, 0x00} // 31 1
	,{0x42, 0x61, 0x51, 0x49, 0x46} // 32 2
	,{0x21, 0x41, 0x45, 0x4b, 0x31} // 33 3
	,{0x18, 0x14, 0x12, 0x7f, 0x10} // 34 4
	,{0x27, 0x45, 0x45, 0x45, 0x39} // 35 5
	,{0x3c, 0x4a, 0x49, 0x49, 0x30} // 36 6
	,{0x01, 0x71, 0x09, 0x05, 0x03} // 37 7
	,{0x36, 0x49, 0x49, 0x49, 0x36} // 38 8
	,{0x06, 0x49, 0x49, 0x29, 0x1e} // 39 9
	,{0x00, 0x36, 0x36, 0x00, 0x00} // 3a :
	,{0x00, 0x56, 0x36, 0x00, 0x00} // 3b ;
	,{0x08, 0x14, 0x22, 0x41, 0x00} // 3c <
	,{0x14, 0x14, 0x14, 0x14, 0x14} // 3d =
	,{0x00, 0x41, 0x22, 0x14, 0x08} // 3e >
	,{0x02, 0x01, 0x51, 0x09, 0x06} // 3f ?
	,{0x32, 0x49, 0x79, 0x41, 0x3e} // 40 @
	,{0x7e, 0x11, 0x11, 0x11, 0x7e} // 41 A
	,{0x7f, 0x49, 0x49, 0x49, 0x36} // 42 B
	,{0x3e, 0x41, 0x41, 0x41, 0x22} // 43 C
	,{0x7f, 0x41, 0x41, 0x22, 0x1c} // 44 D
	,{0x7f, 0x49, 0x49, 0x49, 0x41} // 45 E
	,{0x7f, 0x09, 0x09, 0x09, 0x01} // 46 F
	,{0x3e, 0x41, 0x49, 0x49, 0x7a} // 47 G
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
	,{0x02, 0x04, 0x08, 0x10, 0x20} // 5c backslash
	,{0x00, 0x41, 0x41, 0x7f, 0x00} // 5d ]
	,{0x04, 0x02, 0x01, 0x02, 0x04} // 5e ^
	,{0x40, 0x40, 0x40, 0x40, 0x40} // 5f _
	,{0x00, 0x06, 0x05, 0x03, 0x00} // 60 ` -> degree
	,{0x20, 0x54, 0x54, 0x54, 0x78} // 61 a
	,{0x7f, 0x48, 0x44, 0x44, 0x38} // 62 b
	,{0x38, 0x44, 0x44, 0x44, 0x20} // 63 c
	,{0x38, 0x44, 0x44, 0x48, 0x7f} // 64 d
	,{0x38, 0x54, 0x54, 0x54, 0x18} // 65 e
	,{0x08, 0x7e, 0x09, 0x01, 0x02} // 66 f
	,{0x0c, 0x52, 0x52, 0x52, 0x3e} // 67 g
	,{0x7f, 0x08, 0x04, 0x04, 0x78} // 68 h
	,{0x00, 0x44, 0x7d, 0x40, 0x00} // 69 i
	,{0x20, 0x40, 0x44, 0x3d, 0x00} // 6a j 
	,{0x7f, 0x10, 0x28, 0x44, 0x00} // 6b k
	,{0x00, 0x41, 0x7f, 0x40, 0x00} // 6c l
	,{0x7c, 0x04, 0x18, 0x04, 0x78} // 6d m
	,{0x7c, 0x08, 0x04, 0x04, 0x78} // 6e n
	,{0x38, 0x44, 0x44, 0x44, 0x38} // 6f o
	,{0x7c, 0x14, 0x14, 0x14, 0x08} // 70 p
	,{0x08, 0x14, 0x14, 0x18, 0x7c} // 71 q
	,{0x7c, 0x08, 0x04, 0x04, 0x08} // 72 r
	,{0x48, 0x54, 0x54, 0x54, 0x20} // 73 s
	,{0x04, 0x3f, 0x44, 0x40, 0x20} // 74 t
	,{0x3c, 0x40, 0x40, 0x20, 0x7c} // 75 u
	,{0x1c, 0x20, 0x40, 0x20, 0x1c} // 76 v
	,{0x3c, 0x40, 0x30, 0x40, 0x3c} // 77 w
	,{0x44, 0x28, 0x10, 0x28, 0x44} // 78 x
	,{0x0c, 0x50, 0x50, 0x50, 0x3c} // 79 y
	,{0x44, 0x64, 0x54, 0x4c, 0x44} // 7a z
};
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

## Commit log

2011-10-12 initial commit of project files
    [hike data logger v3.brd, hike data logger v3.sch, hike data logger.brd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]
2011-10-13 Added silkscreen labels for all parts to the Mini layout file, to make it easier to tell what goes where during assembly. Removed the external EEPROM from the Mini schematic and layout. Revised the R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
    [hike data logger v3.brd, hike data logger v3.sch]
2011-10-16 Revised the Mini layout so components aren't under the battery holder anymore. Changed the default Mini project settings to disable the optional shake sensor and related trip timer feature.
    [hike data logger v3.brd, hike data logger v3.sch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]
2011-10-19 Logger Classic layout updates: - rotated the ISP header 180 degrees - fixed the ISP silkscreen label - updated the bottom silkscreen text - moved the standoff holes in from the board edges slightly -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
    [hike data logger.brd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]
2011-10-23 - created a PC sync utility called "blsync" to download graphs and snapshot data from the Logger over a USB-serial connection the utility's source code and .exe are in the blsync subdirectory - added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
    [avrsensors.c, blsync.h, bmp085.c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]
2011-10-27 - added schematics, layout, and Gerbers for blsync adapter board - updated firmware to leave MOSI high at the conclusion of a write (necessary when it doubles as a serial transmit pin)
    [blsync.brd, blsync.sch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]
2011-10-29 - added a metric/imperial units option - made lots of code size optimizations - removed the clock calibration code
2011-10-31 More program size optimizations. Saved about 3K. - replaced wire/twi code with a minimal i2c implementation - replaced auto-constructed version string with a standard "1.0.0" style manually-entered s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
    [bmp085.c, hikea.c, i2c.c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]
2011-10-31 more small program size reductions in bmp085 and i2c code
2011-11-01 Added new Backwoods logo to the unlock screen for both the Mini and Classic Fixed capital T in font Removed "EEPROM sig OK" string, added "Sensor init..." string
    [hikea.c]
2011-11-10 Key debounce and repeat improvements: - improved the debounce logic, allowing for faster button pushes without glitches - fixed a crash bug that occurred if you held down PREV or NEXT while on one of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
    [hikea.c]
2011-11-10 fixed hibernation wake-up timeout
    [hikea.c]
2011-11-20 The blsync utility will now try several alternate bit rates, if it's unable to communicate with the Logger at the default rate. Fixed the transmission of the Logger firmware version number to blsync.
    [blsync.h, hikea.c, serial.c]
2011-12-08 Fixed "unimplemented" appearing on the lock screen, if LOCKSCREEN_DATA_DISPLAY is enabled but TRACK_DAILYHIGHLOW is not.
    [hikea.c]

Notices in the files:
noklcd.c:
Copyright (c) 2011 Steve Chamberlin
